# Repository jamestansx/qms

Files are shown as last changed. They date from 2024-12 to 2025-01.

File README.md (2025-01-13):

# Queue Management System

## TODO
- [x] update queue to wearables to vibrate
- [x] fix bug where queue is not updating its priority

## SETUP

- User UI:
```sh
$ # To run the app
$ fvm flutter run --dart-define=BASEURL=<api-url>
$ # To build the app
$ fvm flutter build apk --release --dart-define=BASEURL=<api-url>
```

- Management UI:
```sh
$ # To run the app (optionally --release)
$ fvm flutter run -d web-server --web-port 8080 --web-hostname 0.0.0.0 --dart-define=BASEURL=<api-url>
```

- backend:
```sh
$ # To start the server
$ BASEURL=<api-url> cargo run --release
```

- firmware:
```sh
$ # Only for arduino-cli
$ ./build.sh <port-name>
```

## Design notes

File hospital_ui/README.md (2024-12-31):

# qms_staff

User Interface for Queue Management System (Staff Interface)

## Getting Started

This project is a starting point for a Flutter application.

A few resources to get you started if this is your first Flutter project:

- [Lab: Write your first Flutter app](https://docs.flutter.dev/get-started/codelab)
- [Cookbook: Useful Flutter samples](https://docs.flutter.dev/cookbook)

For help getting started with Flutter development, view the
[online documentation](https://docs.flutter.dev/), which offers tutorials,
samples, guidance on mobile development, and a full API reference.

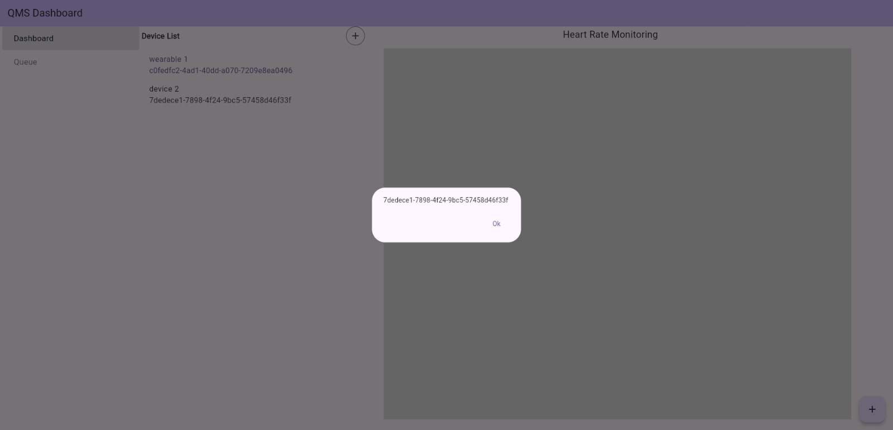
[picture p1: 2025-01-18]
docs/pictures/dashboard_add_device_uuid.jpeg

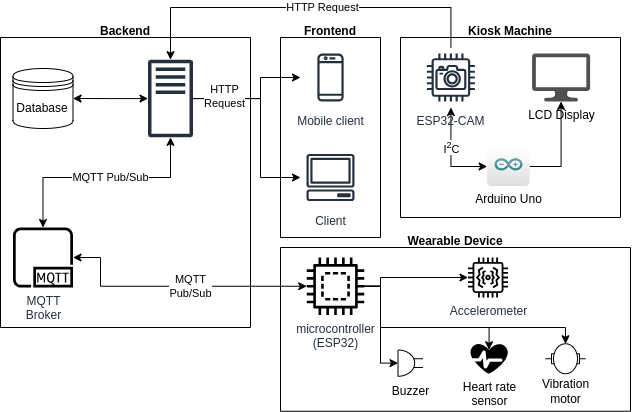
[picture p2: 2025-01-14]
docs/block_diagram.png

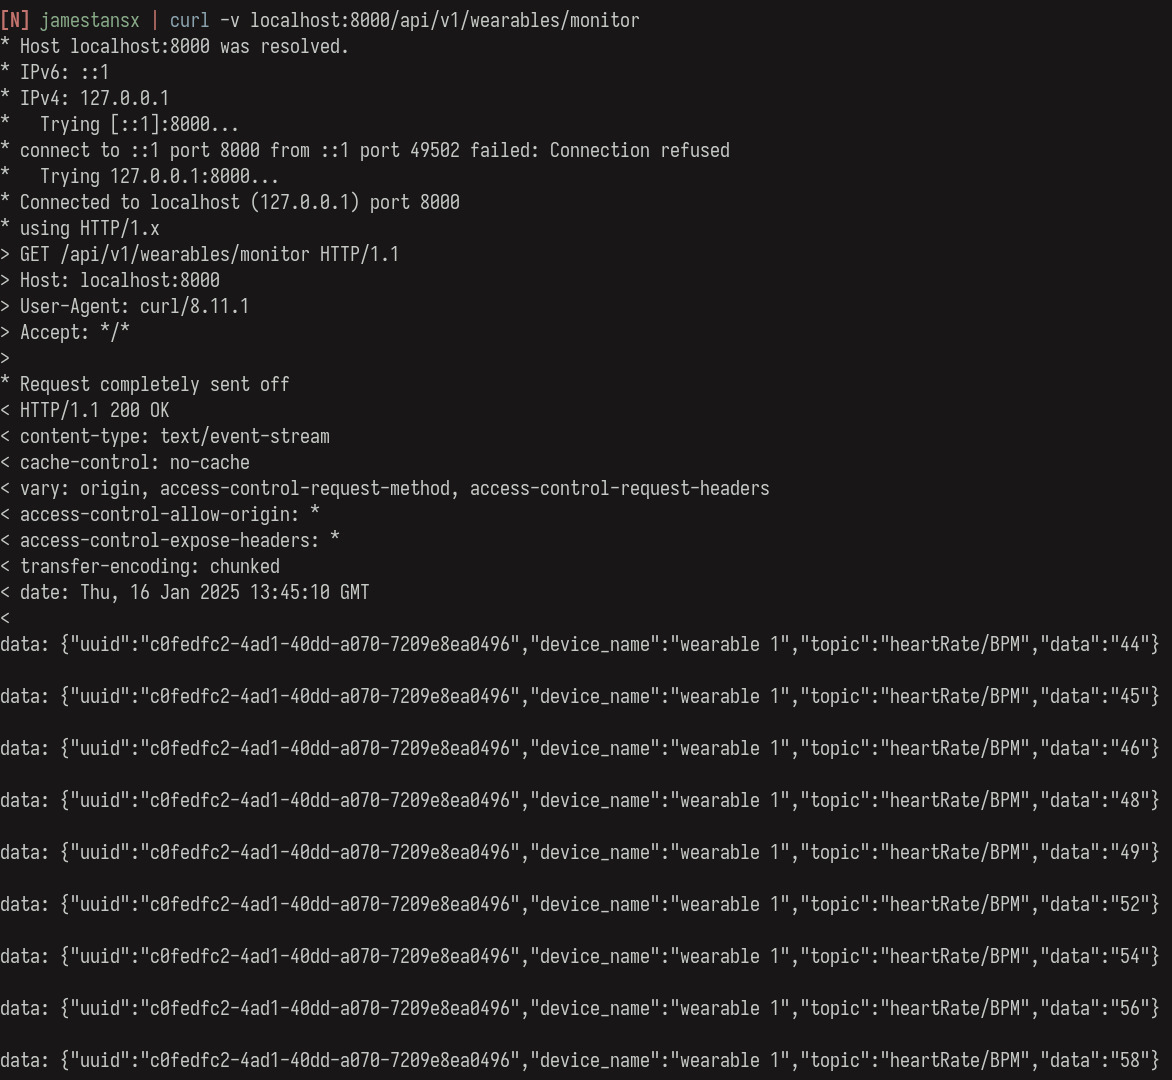
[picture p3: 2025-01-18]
docs/pictures/sse_heart_rate.jpeg

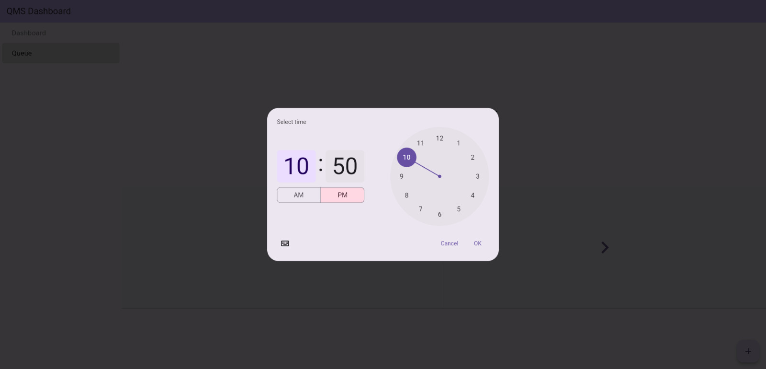
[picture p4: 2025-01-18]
docs/pictures/add_appointment_time.jpeg

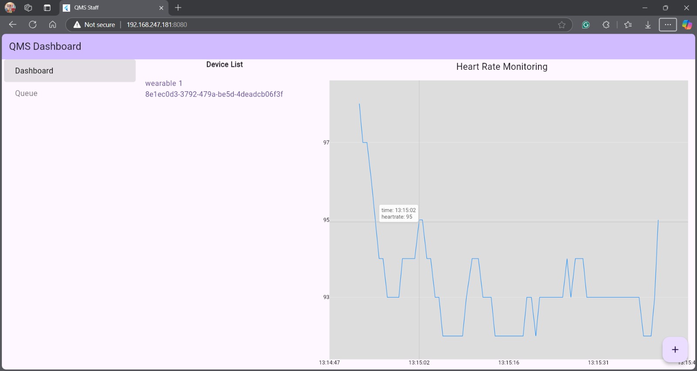
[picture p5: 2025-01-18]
docs/pictures/dashboard_heart_rate_monitor.jpeg

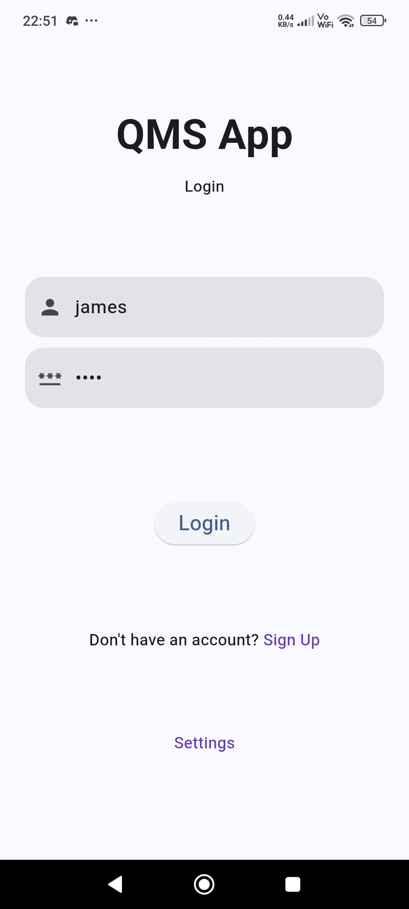
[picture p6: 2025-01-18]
docs/pictures/flutter_login_page.jpeg

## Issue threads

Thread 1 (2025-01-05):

wip(issue): Client ESP32 (wearables) failed to connect with each of two servers namely ("ESP32") and ("ESP32_1")

NgWH5555, 2025-01-05:
```cpp
//(Client ESP32, Wearables)
#include <BLEDevice.h>
#include <WiFi.h>
#include <PubSubClient.h>

const char* ssid = "DT105_2.4GHz@unifi";  // Wi-Fi SSID
const char* password = "112233DT";  // Wi-Fi Password
const char* mqtt_server = "192.168.0.7";  // MQTT Server IP
const int mqtt_port = 1883;  // MQTT Port
const char* mqtt_topic = "location/RSSI";  // MQTT Topic

WiFiClient espClient;
PubSubClient mqttClient(espClient);

static BLEUUID serviceUUID("4fafc201-1fb5-459e-8fcc-c5c9c331914b");  // Common Service UUID

// Unique Characteristic UUIDs for Beacon 1 and Beacon 2
static BLEUUID beacon1CharUUID("beb5483e-36e1-4688-b7f5-ea07361b26a8");
static BLEUUID beacon2CharUUID("beb5483e-36e1-4688-b7f5-ea07361b26a9");

static boolean doConnect = false;
static boolean connectedBeacon1 = false;
static boolean connectedBeacon2 = false;
static BLERemoteCharacteristic* pRemoteCharacteristic1;
static BLERemoteCharacteristic* pRemoteCharacteristic2;
static BLEAdvertisedDevice* myDevice = nullptr;
static BLEClient* pClient = nullptr;

int previousRSSI1 = 0;  // Previous RSSI for Beacon 1
int previousRSSI2 = 0;  // Previous RSSI for Beacon 2

// Variables to store RSSI for ESP32 and ESP32_1
int rssiESP32 = -1000;
int rssiESP32_1 = -1000;

// 1. Declare the callback class MyClientCallback before it is used
class MyClientCallback : public BLEClientCallbacks {
  void onConnect(BLEClient* pclient) {}

  void onDisconnect(BLEClient* pclient) {
    // Handle disconnect logic here
    if (pclient == pClient) {
      connectedBeacon1 = false;
      connectedBeacon2 = false;
    }
  }
};

// 2. Declare the connectToBeacon function before its usage
bool connectToBeacon(BLEAdvertisedDevice* advertisedDevice, BLEUUID beaconUUID) {
  pClient = BLEDevice::createClient();
  pClient->setClientCallbacks(new MyClientCallback());  // Use the callback here
  if (pClient->connect(advertisedDevice)) {
    Serial.println(F(" - Connected to Beacon"));

    BLERemoteService* pRemoteService = pClient->getService(serviceUUID);
    if (pRemoteService == nullptr) {
      Serial.println(F("Failed to find our service UUID"));
      pClient->disconnect();
      return false;
    }

    BLERemoteCharacteristic* pRemoteCharacteristic = pRemoteService->getCharacteristic(beaconUUID);
    if (pRemoteCharacteristic == nullptr) {
      Serial.println(F("Failed to find the characteristic for Beacon"));
      pClient->disconnect();
      return false;
    }

    return true;
  }
  return false;
}

// 3. Declare the callback class MyAdvertisedDeviceCallbacks before its usage
class MyAdvertisedDeviceCallbacks : public BLEAdvertisedDeviceCallbacks {
  void onResult(BLEAdvertisedDevice advertisedDevice) {
    Serial.print(F("BLE Advertised Device found: "));
    Serial.println(advertisedDevice.toString().c_str());

    // Capture the RSSI value
    int rssi = advertisedDevice.getRSSI();
    String deviceName = advertisedDevice.getName();

    // Check if the device is advertising the common service UUID
    if (advertisedDevice.haveServiceUUID() && advertisedDevice.isAdvertisingService(serviceUUID)) {
      BLEDevice::getScan()->stop();
      myDevice = new BLEAdvertisedDevice(advertisedDevice);

      // If it's ESP32, store the RSSI for ESP32
      if (deviceName == "ESP32") {
        rssiESP32 = rssi;
      }

      // If it's ESP32_1, store the RSSI for ESP32_1
      if (deviceName == "ESP32_1") {
        rssiESP32_1 = rssi;
      }

      // Compare the RSSI of ESP32 and ESP32_1
      if (rssiESP32 > rssiESP32_1) {
        Serial.println("Connected to ESP32 (stronger RSSI)");
        if (!connectedBeacon1) {
          if (connectToBeacon(myDevice, beacon1CharUUID)) {
            connectedBeacon1 = true;
            Serial.println("Connected to Beacon 1");
          }
        }
      } else {
        Serial.println("Connected to ESP32_1 (stronger RSSI)");
        if (!connectedBeacon2) {
          if (connectToBeacon(myDevice, beacon2CharUUID)) {
            connectedBeacon2 = true;
            Serial.println("Connected to Beacon 2");
          }
        }
      }
    }
  }
};

void connectToMQTT() {
  while (!mqttClient.connected()) {
    Serial.print(F("Connecting to MQTT..."));
    if (mqttClient.connect("ESP32_Client")) {
      Serial.println(F("connected"));
    } else {
      Serial.print(F("failed, rc="));
      Serial.print(mqttClient.state());
      delay(5000);
    }
  }
}

void scanAndConnectToBeacons() {
  BLEScan* pBLEScan = BLEDevice::getScan();
  pBLEScan->setAdvertisedDeviceCallbacks(new MyAdvertisedDeviceCallbacks());
  pBLEScan->setInterval(1349);
  pBLEScan->setWindow(449);
  pBLEScan->setActiveScan(true);
  pBLEScan->start(5, false);
}

void setup() {
  Serial.begin(115200);
  BLEDevice::init("");  // Initialize BLE device

  WiFi.begin(ssid, password);
  while (WiFi.status() != WL_CONNECTED) {
    delay(1000);
  }
  Serial.println("Connected to Wi-Fi");
  mqttClient.setServer(mqtt_server, mqtt_port);
  connectToMQTT();

  scanAndConnectToBeacons();  // Start scanning and connecting to Beacons
}

void loop() {
  if (!mqttClient.connected()) {
    connectToMQTT();
  }
  mqttClient.loop();

  // If both Beacons are connected, you can now proceed to handle other logic
  if (connectedBeacon1 && connectedBeacon2) {
    Serial.println("Both Beacons are connected!");
    // Proceed with other tasks, e.g., getting RSSI or sending MQTT messages
  } else {
    Serial.println("Waiting for connections...");
  }

  delay(2000);  // Delay to reduce the frequency of the scan loop
}

```
```cpp
//(Server1: ESP32)
#include <BLEDevice.h>
#include <BLEServer.h>
#include <BLEUtils.h>
#include <BLE2902.h>

BLEServer* pServer = NULL;
BLECharacteristic* pCharacteristic = NULL;
BLEDescriptor *pDescr;
BLE2902 *pBLE2902;

bool deviceConnected = false;
bool oldDeviceConnected = false;
uint32_t value = 0;

// See the following for generating UUIDs:
// https://www.uuidgenerator.net/

#define SERVICE_UUID        "4fafc201-1fb5-459e-8fcc-c5c9c331914b"
#define CHARACTERISTIC_UUID "beb5483e-36e1-4688-b7f5-ea07361b26a8"

class MyServerCallbacks: public BLEServerCallbacks {
    void onConnect(BLEServer* pServer) {
      deviceConnected = true;
    };

    void onDisconnect(BLEServer* pServer) {
      deviceConnected = false;
    }
};

void setup() {
  Serial.begin(115200);

  // Create the BLE Device
  BLEDevice::init("ESP32");

  // Create the BLE Server
  pServer = BLEDevice::createServer();
  pServer->setCallbacks(new MyServerCallbacks());

  // Create the BLE Service
  BLEService *pService = pServer->createService(SERVICE_UUID);

  // Create a BLE Characteristic
  pCharacteristic = pService->createCharacteristic(
                      CHARACTERISTIC_UUID,
                      BLECharacteristic::PROPERTY_NOTIFY
                    );           

  // Create a BLE Descriptor

  pDescr = new BLEDescriptor((uint16_t)0x2901);
  pDescr->setValue("A very interesting variable");
  pCharacteristic->addDescriptor(pDescr);

  pBLE2902 = new BLE2902();
  pBLE2902->setNotifications(true);
  pCharacteristic->addDescriptor(pBLE2902);

  // Start the service
  pService->start();

  // Start advertising
  BLEAdvertising *pAdvertising = BLEDevice::getAdvertising();
  pAdvertising->addServiceUUID(SERVICE_UUID);
  pAdvertising->setScanResponse(false);
  pAdvertising->setMinPreferred(0x0);  // set value to 0x00 to not advertise this parameter
  BLEDevice::startAdvertising();
  Serial.println("Waiting a client connection to notify...");
}

void loop() {
    // notify changed value
    if (deviceConnected) {
        pCharacteristic->setValue(value);
        pCharacteristic->notify();
        value++;
        delay(1000);
    }
    // disconnecting
    if (!deviceConnected && oldDeviceConnected) {
        delay(500); // give the bluetooth stack the chance to get things ready
        pServer->startAdvertising(); // restart advertising
        Serial.println("start advertising");
        oldDeviceConnected = deviceConnected;
    }
    // connecting
    if (deviceConnected && !oldDeviceConnected) {
        // do stuff here on connecting
        oldDeviceConnected = deviceConnected;
    }
}
```
```cpp
\\(Server2: ESP32_1）
#include <BLEDevice.h>
#include <BLEServer.h>
#include <BLEUtils.h>
#include <BLE2902.h>

BLEServer* pServer = NULL;
BLECharacteristic* pCharacteristic = NULL;
BLEDescriptor *pDescr;
BLE2902 *pBLE2902;

bool deviceConnected = false;
bool oldDeviceConnected = false;
uint32_t value = 0;

// See the following for generating UUIDs:
// https://www.uuidgenerator.net/

#define SERVICE_UUID        "4fafc201-1fb5-459e-8fcc-c5c9c331914b"
#define CHARACTERISTIC_UUID "beb5483e-36e1-4688-b7f5-ea07361b26a9"

class MyServerCallbacks: public BLEServerCallbacks {
    void onConnect(BLEServer* pServer) {
      deviceConnected = true;
    };
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
jamestansx, 2025-01-06:
```cpp
void perform_post_request(const char *uuid){
  // Create JSON body with the UUID
  String json_str = String("{\"uuid\": \"");
  json_str += String(uuid);
  json_str += String(\"}");

  int payload_len = json_str.length() + 1;
  char payload[payload_len];
  json_str.toCharArray(payload, payload_len);

  esp_http_client_config_t config = {
    .url = "http://192.168.0.2:3000/api/v1/queues/verify", //Full URL
  };

  esp_http_client_handle_t client = esp_http_client_init(&config);

  if(client == NULL){
    ESP_LOGE(TAG, "Failed to initialize HTTP client");
    return;
  }

  // Set POST method
  esp_http_client_set_method(client, HTTP_METHOD_POST);

  // Set POST body
  esp_http_client_set_post_field(client, payload, strlen(payload));

  // Add headers if necessary (e.g., Content-Type)
  esp_http_client_set_header(client, "Content-Type", "application/json");

  //Perform POST request
  esp_err_t err = esp_http_client_perform(client);
  if (err == ESP_OK) {
        ESP_LOGI(TAG, "HTTP POST Status = %d, content_length = %" PRId64,
                 esp_http_client_get_status_code(client),
                 esp_http_client_get_content_length(client));
    } else {
        ESP_LOGE(TAG, "HTTP POST request failed: %s", esp_err_to_name(err));
    }

  // Clean up
  esp_http_client_cleanup(client);
}

```

jamestansx, 2025-01-06:
```cpp
#define MAX_HTTP_OUTPUT_BUFFER 2048
// #define MIN(x, y) ((x < y) ? x : y)

esp_err_t _http_ev_handler(esp_http_client_event_t *ev)
{
  static char *out_buf;
  static int out_len;

  if (ev->event_id != HTTP_EVENT_ON_DATA) {
    return ESP_OK;
  }

  if (out_len == 0 && ev->user_data) {
    memset(ev->user_data, 0, MAX_HTTP_OUTPUT_BUFFER);
  }

  if (esp_http_client_is_chunked_response(ev->client)) {
    return ESP_OK;
  }

  int copy_len = 0;
  if (ev->user_data) {
    // The last byte in ev->user_data is kept for the NULL character in case of out-of-bound access.
    copy_len = MIN(ev->data_len, (MAX_HTTP_out_buf - out_len));
    if (copy_len) {
      memcpy(ev->user_data + out_len, ev->data, copy_len);
    }
  } else {
    int content_len = esp_http_client_get_content_length(ev->client);
    if (out_buf == NULL) {
      out_buf = (char *) calloc(content_len + 1, sizeof(char));
      out_len = 0;
      if (out_buf == NULL) {
        return ESP_FAIL;
      }
    }
    copy_len = MIN(ev->data_len, (content_len - out_len));
    if (copy_len) {
      memcpy(out_buf + out_len, ev->data, copy_len);
    }
  }
  out_len += copy_len;
}

.event_handler = _http_ev_handler;
```

jamestansx, 2025-01-06:
```cpp
esp_err_t _http_ev_handler(esp_http_client_event_t *ev)
{
  static char *out_buf;

  if (ev->event_id != HTTP_EVENT_ON_DATA) {
    return ESP_OK;
  }

  if (esp_http_client_is_chunked_response(ev->client)) {
    return ESP_OK;
  }

  Serial.println("I2C transmission started");
  Wire.beginTransmission(4);
  Wire.write((const uint8_t*)ev->data,ev->data_len);
  Wire.endTransmission();

  return ESP_OK;
}
```

Closed 2025-01-08.

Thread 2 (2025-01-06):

Wearables integration issue

NgWH5555, 2025-01-06:
```cpp
(1. the notification of fall detection process takes so slow like after 10 s to complete)
#define USE_ARDUINO_INTERRUPTS true    // Set up low-level interrupts for accurate BPM math.
#include <BLEDevice.h>
#include <WiFi.h>

#include <PubSubClient.h>
#include <PulseSensorPlayground.h>     // Includes the PulseSensorPlayground Library.

#include <Wire.h>
#include <MPU6050.h>                   // Ensure the MPU6050 library is compatible with ESP32.
#include <math.h>

#define SIZEOF(a) (sizeof(a) / sizeof(*a))

#define DEVICE_UUID "0ea57b2b-8dbe-41cd-9780-f7d1d237839c"

//In the DT house
const char* ssid = "DT105_2.4GHz@unifi";
const char* password = "112233DT";
const char* mqtt_server = "192.168.0.7";

//UTeM
//const char* ssid = "UTeM-Net";
//const char* password = "1UTeM@PPPK";
//const char* mqtt_server = "10.131.129.57";

////Ng
//const char* ssid = "Michael NG";
//const char* password = "weihan123456";
//const char* mqtt_server = "172.20.10.3";

const int mqtt_port = 1883;
const char* mqtt_topic_location= "location/RSSI";
const char* mqtt_topic_heart= "heartRate/BPM";                // Topic to publish heart rate data.
const char* mqtt_topic_heartAlert = "heartRate/heartAlert";
const char* mqtt_topic_amplitude = "accelerometer/amplitude";
const char* mqtt_topic_angular = "accelerometer/ang";
const char* mqtt_topic_fallAlert = "accelerometer/fall";      // Topic for fall detection.
const char* mqtt_sub_queue = "queue/status";                  //Topic for queue status update
WiFiClient espClient;
PubSubClient mqttClient(espClient);

//Variables: BLE
const BLEUUID known_beacons[] = {
  BLEUUID("beb5483e-36e1-4688-b7f5-ea07361b26a8"),
  BLEUUID("beb5483e-36e1-4688-b7f5-ea07361b26a9")
};
static boolean doScan = false;
static BLERemoteCharacteristic* pRemoteCharacteristic;
static BLEAdvertisedDevice* myDevice;
static BLEClient* pClient = nullptr;
int previousRSSI = 0;
BLEScan* pBLEScan;

struct BleBeacon {
  BLEUUID uuid;
  int rssi;
};
BleBeacon bleBeacons[SIZEOF(known_beacons)] = {};

//Variables: heartrate
const int PulseWire =34;       // PulseSensor PURPLE WIRE connected to GPIO36 (ADC1_CH0).
const int LED = 2;      // Onboard LED on ESP32 (usually GPIO2).
int Threshold = 550;            // Threshold value to detect beats.

bool recordingStarted = false;       // Flag to track when measurement starts
PulseSensorPlayground pulseSensor;  // Creates an instance of the PulseSensorPlayground object.

//variables: falldown
// MPU6050 Configuration
const int MPU_addr = 0x68; // I2C address of the MPU-6050
int16_t AcX, AcY, AcZ, Tmp, GyX, GyY, GyZ;
float ax = 0, ay = 0, az = 0, gx = 0, gy = 0, gz = 0;
boolean fall = false; // Stores if a fall has occurred
boolean trigger1 = false; // Stores if first trigger (lower threshold) has occurred
boolean trigger2 = false; // Stores if second trigger (upper threshold) has occurred
boolean trigger3 = false; // Stores if third trigger (orientation change) has occurred
byte trigger1count = 0; // Stores the counts past since trigger 1 was set true
byte trigger2count = 0; // Stores the counts past since trigger 2 was set true
byte trigger3count = 0; // Stores the counts past since trigger 3 was set true
int angleChange = 0;

//Time intervals for each operation
unsigned long prev_time_acce, prev_time_queue, prev_time_scan;
const int SAMPLE_INTERVAL = 100; // milliseconds

unsigned long prev_time_heart;
const int SAMPLE_INTERVAL_HEART = 100; // milliseconds

//Vibration DC motor
#define vibrationdc 23
static bool motorActive = false;
static unsigned long motorStartTime = 0;
const unsigned long motorVibrationDuration = 500;

void connectToMQTT() {
  while (!mqttClient.connected()) {
    Serial.print(F("Connecting to MQTT..."));
    if (mqttClient.connect("ESP32_Client")) {
      Serial.println(F("connected"));
      uint16_t packetIdSub = mqttClient.subscribe(mqtt_sub_queue, 2);
      Serial.print("Subscribing at QUEUE, packetId: ");
      Serial.println(packetIdSub);
      delay(3000);
    } else {
      Serial.print(F("failed, rc="));
      Serial.print(mqttClient.state());

      delay(5000);
    }
  }
}

String printAndSendRSSI() {
  String uuid = "";
  int rssi = 0;
  for (int i = 0; i < SIZEOF(bleBeacons); i++) {
    if (uuid.isEmpty()) {
      rssi = bleBeacons[i].rssi;
      uuid = bleBeacons[i].uuid.toString();
      continue;
    }

    if (bleBeacons[i].rssi > rssi) {
      rssi = bleBeacons[i].rssi;
      uuid = bleBeacons[i].uuid.toString();
    }
  }

  mqttClient.publish(mqtt_topic_location, uuid.c_str());

  return uuid;
}

class MyAdvertisedDeviceCallbacks : public BLEAdvertisedDeviceCallbacks {
  void onResult(BLEAdvertisedDevice advertisedDevice) {
    BLEUUID service = advertisedDevice.getServiceUUID();
    //Serial.print(F("BLE Advertised Device found: "));
    //Serial.println(advertisedDevice.toString().c_str());

    for (int i = 0; i < SIZEOF(known_beacons); i++) {
      if (service.equals(known_beacons[i])) {
        bleBeacons[i].uuid = service;
        bleBeacons[i].rssi = advertisedDevice.getRSSI();
      }
    }
  }
};

void connectWifi(){
  WiFi.begin(ssid, password);
  while (WiFi.status() != WL_CONNECTED) {
    delay(1000);
  }
  Serial.println("Connected to Wi-Fi");
  //Serial.print("IP address: ");
  //Serial.println(WiFi.localIP());

}

//server/queue  onMqttMessage() is responsible for obtaining MQTT message from the subscribed topic
//and controlling the (outside exp: LED). The string variable 'messageTemp' holds the MQTT message.
void onMqttMessage(char* topic, byte* payload, unsigned int length) {
  unsigned long currTime_queue = millis();

  if (currTime_queue - prev_time_queue >= SAMPLE_INTERVAL) {
    prev_time_queue = currTime_queue;
    Serial.println("\n Publish received.");
    Serial.print("Topic: ");
    Serial.println(topic);
    String messageTemp;
    for (int i = 0; i < length; i++){
      messageTemp += (char)payload[i];
    }
    Serial.print("Message: ");
    Serial.println(messageTemp);

    digitalWrite(vibrationdc, HIGH);
    motorActive = true;
    motorStartTime = millis();
  }

  //Turn off motor after the set duration
  if(motorActive && (millis() - motorStartTime >= motorVibrationDuration)){
    digitalWrite(vibrationdc, LOW);
    motorActive = false;
  }
}

void heartrate() {
  static unsigned long startTime = 0;    // To track the start time of measurement
  static unsigned long lastBeatTime = 0; // Tracks the last time data was sent
  const unsigned long interval = 500;   // Delay interval in milliseconds (adjust as needed)
  int myBPM = pulseSensor.getBeatsPerMinute();

  if (pulseSensor.sawStartOfBeat()) {
    if (!recordingStarted){
      if(startTime == 0){
        startTime = millis();
      }
      if (millis() - startTime >= 4000) {
        Serial.print(" | Heart Rate: N/A");
        recordingStarted = true; // Enable recording after 7 secondsM
        Serial.println("Recording started. Data will now be sent to the MQTT server.");
      }
    } else if (millis() - lastBeatTime >= interval) {
      lastBeatTime = millis(); // Update the last beat time
      Serial.print(" | Heart Rate: ");
      Serial.println(myBPM);
      char payload_heart[50];
      snprintf(payload_heart, 50, "{\"BPM\": %d}", myBPM); // Format data as JSON
      mqttClient.publish(mqtt_topic_heart, payload_heart);
    }
  }
}

/*
 * TODO: Falling detection algorithm description goes here.
 */
void falldown() {
  mpu_read();
  ax = (AcX - 2050) / 16384.00;
  ay = (AcY - 77) / 16384.00;
  az = (AcZ - 1947) / 16384.00;
  gx = (GyX + 270) / 131.07;
  gy = (GyY - 351) / 131.07;
  gz = (GyZ + 136) / 131.07;
  // Calculating Amplitude Vector for 3-axis
  float raw_amplitude = pow(pow(ax, 2) + pow(ay, 2) + pow(az, 2), 0.5);
  float amplitude = raw_amplitude * 10;  // Multiplied by 10 because values are between 0 to 1

  Serial.print(" | Amplitude: ");
  Serial.println(amplitude);
  // Publish acceleration magnitude to MQTT
  char payload_amplitude[50];
  snprintf(payload_amplitude, 50, "{\"Amplitude\": %.2f}", amplitude);
  mqttClient.publish(mqtt_topic_amplitude, payload_amplitude);

  if (amplitude <= 2 && trigger2 == false) { // If AM breaks lower threshold (0.4g)
    trigger1 = true;
    //Serial.println("TRIGGER 1 ACTIVATED");
  }
  if (trigger1 == true) {     // Detects initial potential fall
    trigger1count++;
    if (amplitude >= 12) { // If AM breaks upper threshold (3g)
      trigger2 = true;
      //    Serial.println("TRIGGER 2 ACTIVATED");
      trigger1 = false; trigger1count = 0;
    }
  }
  if (trigger2 == true) {   // Detects high amplitude (impact)
    trigger2count++;
    angleChange = pow(pow(gx, 2) + pow(gy, 2) + pow(gz, 2), 0.5);
    Serial.println(angleChange);
    if (angleChange >= 30 && angleChange <= 400) { // If orientation changes by between 80-100 degrees
      trigger3 = true; trigger2 = false; trigger2count = 0;
      //    Serial.println(angleChange);
      //    Serial.println("TRIGGER 3 ACTIVATED");
    }
  }
  if (trigger3 == true) {   // Monitors orientation changes (e.g. lying on the ground)
    trigger3count++;
      memset(bleBeacons, 0, sizeof(bleBeacons));
   pBLEScan->start(5, false);
    if (trigger3count >= 10) {
      angleChange = pow(pow(gx, 2) + pow(gy, 2) + pow(gz, 2), 0.5);
      //     Serial.println(angleChange);
      if ((angleChange >= 0) && (angleChange <= 10)) { // If orientation changes remain between 0-10 degrees
        fall = true; trigger3 = false; trigger3count = 0;
        //       Serial.println(angleChange);
      }

      else { // User regained normal orientation
        trigger3 = false; trigger3count = 0;
        //       Serial.println("TRIGGER 3 DEACTIVATED");
      }
    }
  }

  if (fall == true && !motorActive) { // In the event of a fall detection

    Serial.println("Fall detected!");
    // Additional logic for alerts (e.g., buzzer, SMS, LED)
    // Publish fall detection event to MQTT
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
NgWH5555, 2025-01-07:
CAN I USE THIS FOR REFRESH THE STATUS OF BLE CONNECTION)

#include <BLEDevice.h>
#include <BLEUtils.h>
#include <BLEScan.h>
#include <BLEClient.h>

#define SERVICE_UUID "your-service-uuid"
#define CHARACTERISTIC_UUID "your-characteristic-uuid"

BLEClient* pClient = nullptr;
bool deviceConnected = false;

// Function to scan for BLE devices with the specified SERVICE UUID
String findDeviceByServiceUUID(const char* serviceUUID) {
    Serial.println("Scanning for BLE devices with the specified service UUID...");
    BLEScan* pBLEScan = BLEDevice::getScan();
    pBLEScan->setActiveScan(true);
    BLEScanResults scanResults = pBLEScan->start(5);  // Scan for 5 seconds

    for (int i = 0; i < scanResults.getCount(); i++) {
        BLEAdvertisedDevice advertisedDevice = scanResults.getDevice(i);
        if (advertisedDevice.haveServiceUUID() && advertisedDevice.isAdvertisingService(BLEUUID(serviceUUID))) {
            Serial.print("Found device: ");
            Serial.println(advertisedDevice.toString().c_str());
            pBLEScan->clearResults();
            return advertisedDevice.getAddress().toString().c_str();
        }
    }

    Serial.println("No device found with the specified service UUID.");
    pBLEScan->clearResults();
    return "";  // Return an empty string if no device is found
}

// Function to connect to BLE device using its address
bool connectToServer(const String& deviceAddress) {
    if (deviceAddress == "") {
        Serial.println("No device address provided. Cannot connect.");
        return false;
    }

    Serial.println("Attempting to connect to BLE server...");
    pClient = BLEDevice::createClient();
    pClient->connect(BLEAddress(deviceAddress.c_str()));  // Connect to
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

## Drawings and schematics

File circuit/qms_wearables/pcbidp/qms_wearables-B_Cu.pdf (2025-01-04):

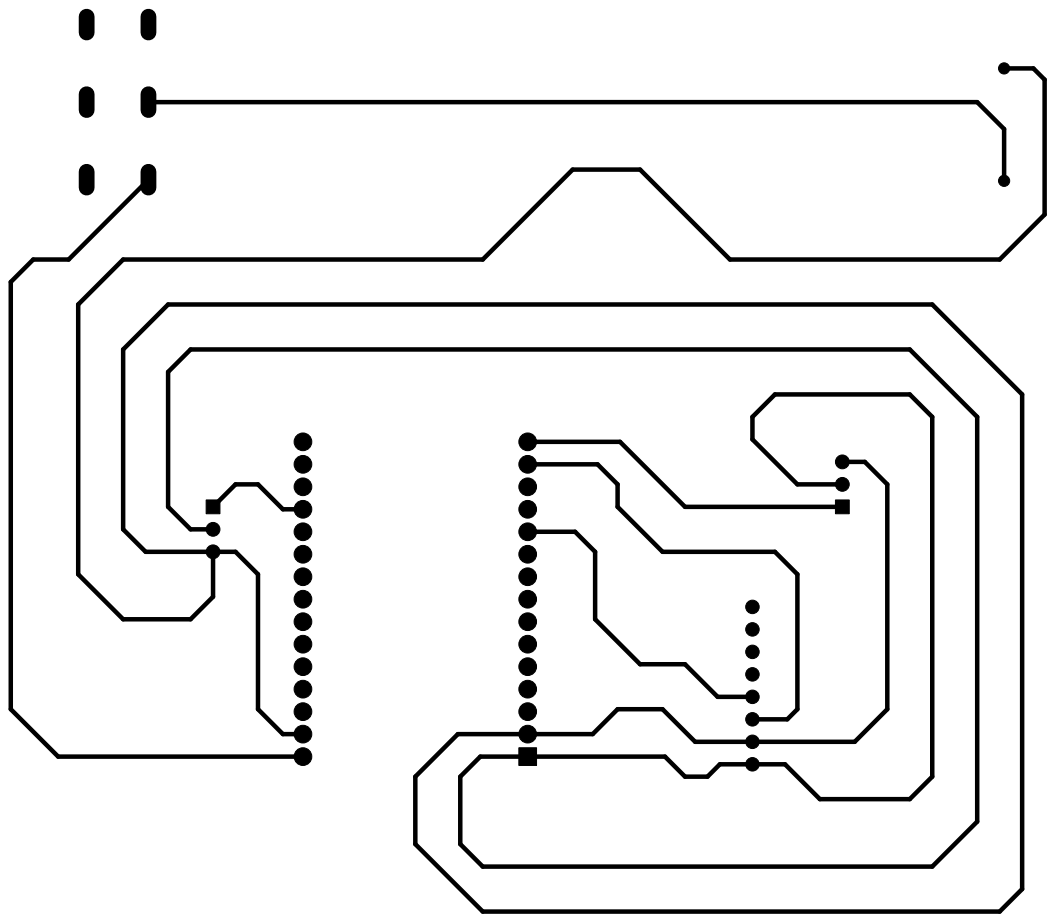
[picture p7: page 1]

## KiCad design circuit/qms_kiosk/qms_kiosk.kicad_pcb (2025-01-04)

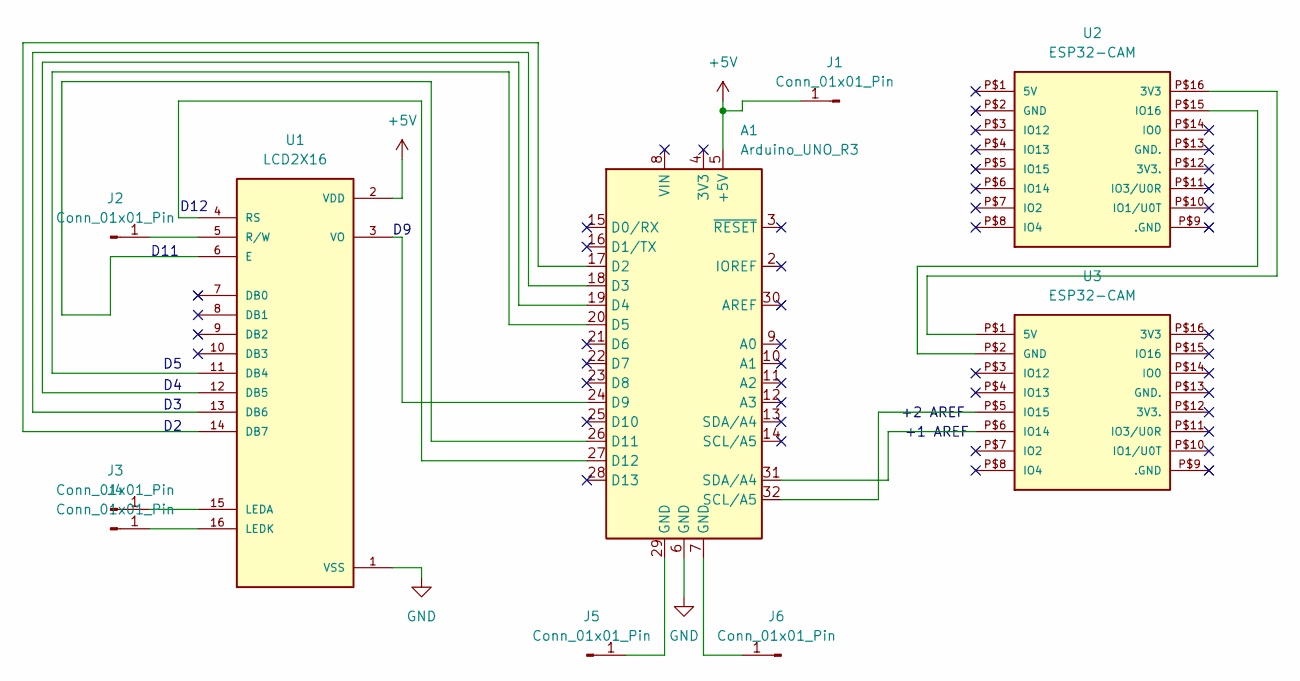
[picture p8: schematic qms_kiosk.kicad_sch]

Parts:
A1: Arduino_UNO_R3
J1, J2, J3, J4, J5, J6: Conn_01x01_Pin; PinHeader_1x01_P2.00mm_Vertical
U1: LCD2X16; LCD_LCD2X16; PARTREV 0
U2, U3: ESP32-CAM

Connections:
+5V: A1.5 (+5V), J1.1, U1.2 (VDD)
GND: A1.6 (GND), U1.1 (VSS)
unnamed: A1.17 (D2), U1.14 (DB7)
unnamed: A1.18 (D3), U1.13 (DB6)
unnamed: A1.19 (D4), U1.12 (DB5)
unnamed: A1.20 (D5), U1.11 (DB4)
unnamed: A1.24 (D9), U1.3 (VO)
unnamed: A1.26 (D11), U1.6 (E)
unnamed: A1.27 (D12), U1.4 (RS)
unnamed: J2.1, U1.5 (R/W)
unnamed: J3.1, U1.15 (LEDA)
unnamed: J4.1, U1.16 (LEDK)
unnamed: A1.29 (GND), J5.1
unnamed: A1.7 (GND), J6.1
unnamed: U2.P$16 (3V3), U3.P$1 (5V)
unnamed: U2.P$15 (IO16), U3.P$2 (GND)
unnamed: A1.31 (SDA/A4), U3.P$6 (IO14)
unnamed: A1.32 (SCL/A5), U3.P$5 (IO15)

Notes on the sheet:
D11
+2 AREF
+1 AREF
D12

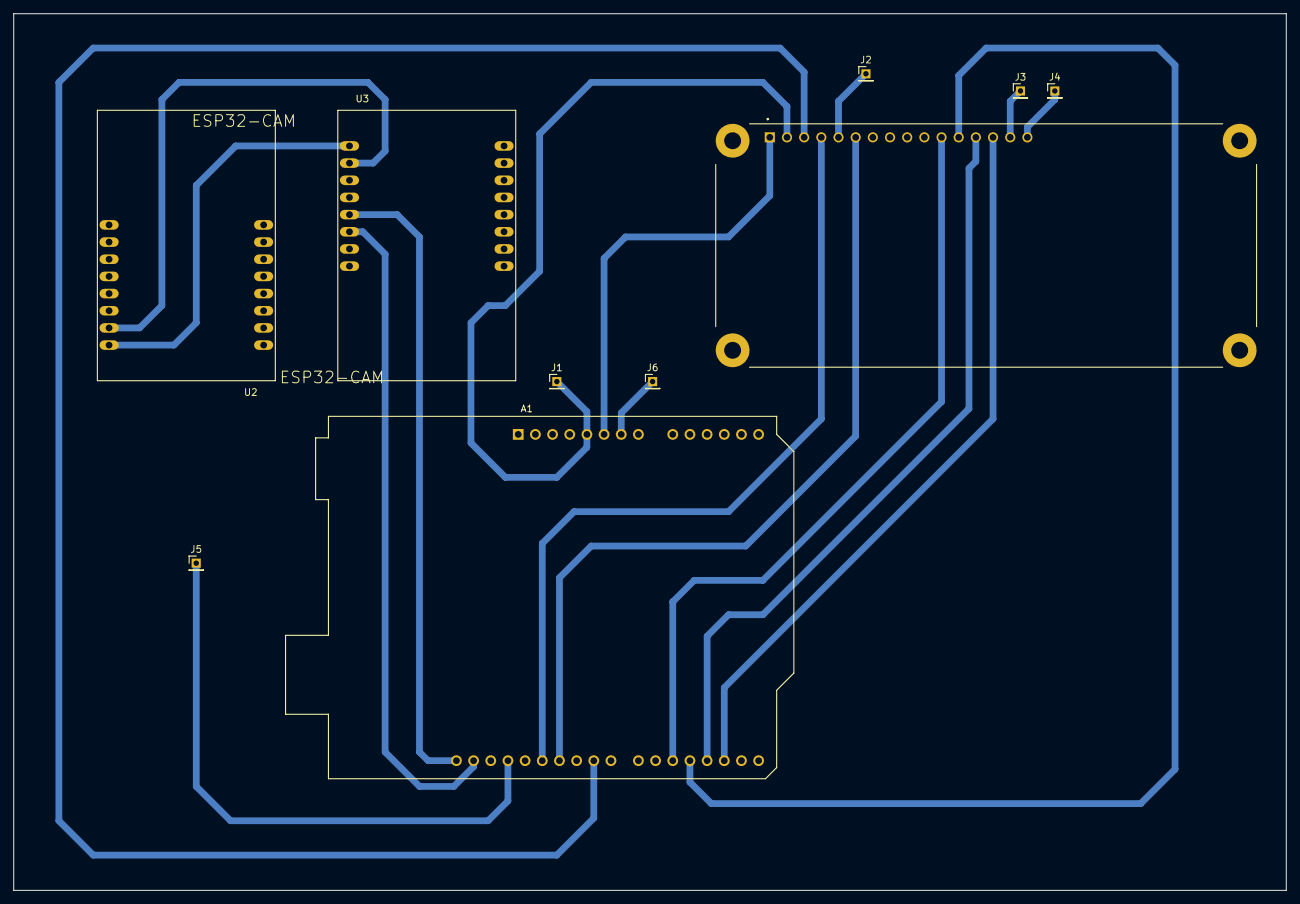
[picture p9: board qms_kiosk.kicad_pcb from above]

Board: 2 copper layers, 188.2 x 129.7 mm, 10 parts (0 on the bottom side), 18 nets.

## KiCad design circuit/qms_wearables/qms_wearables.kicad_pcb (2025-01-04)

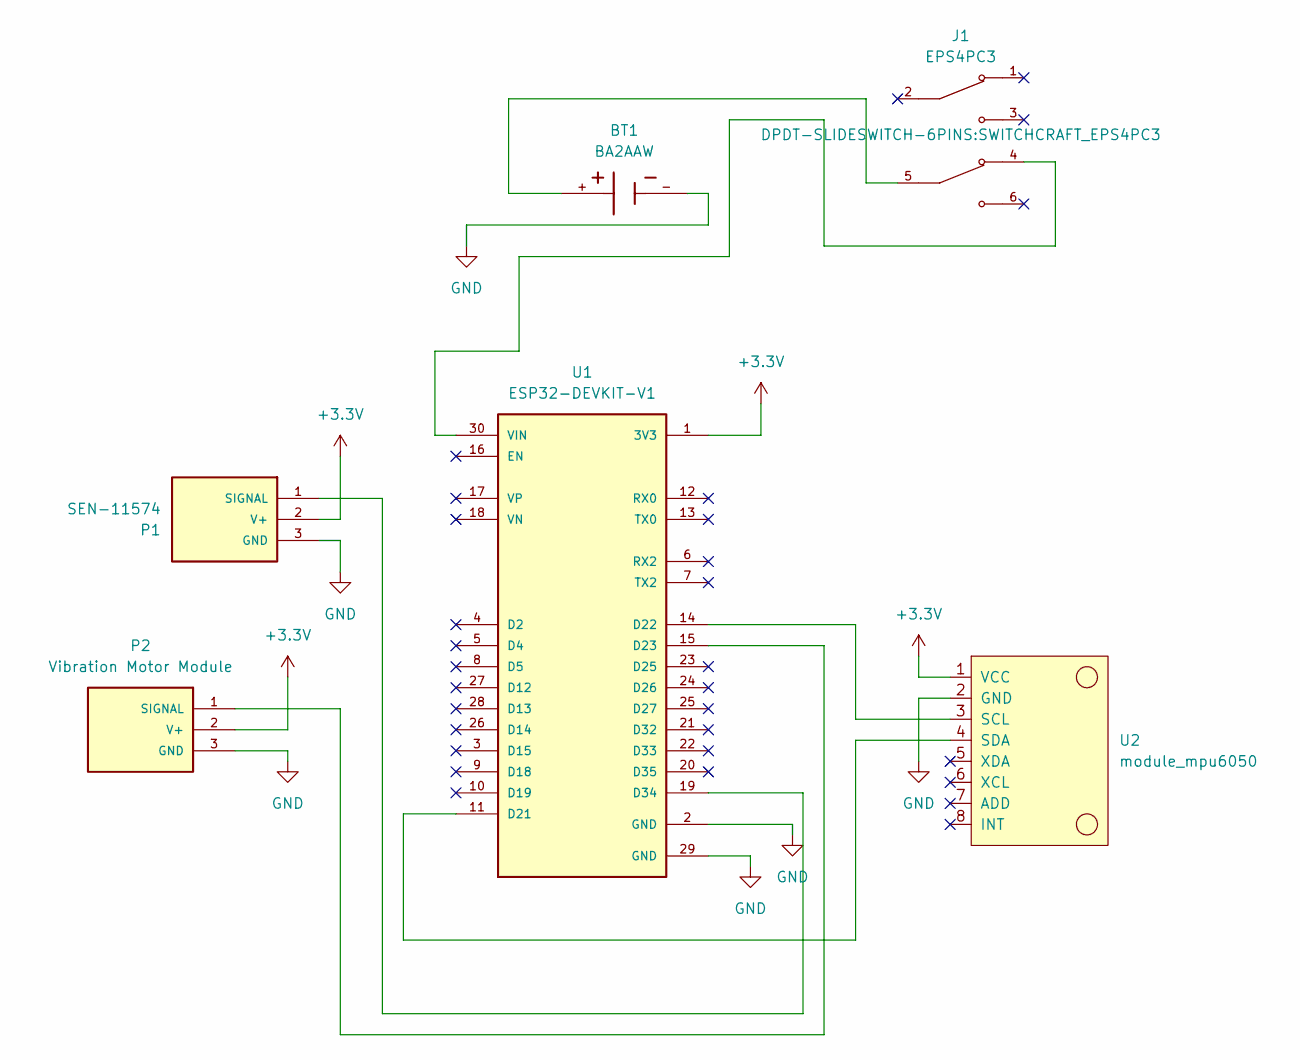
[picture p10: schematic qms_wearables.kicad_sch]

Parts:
BT1: BA2AAW; BAT_BA2AAW; PARTREV E
J1: EPS4PC3; SWITCHCRAFT_EPS4PC3
P1: SEN-11574; XDCR_SEN-11574
P2: Vibration Motor Module; XDCR_Vibration_Motor_Module
U1: ESP32-DEVKIT-V1; MODULE_ESP32_DEVKIT_V1; PARTREV N/A
U2: module_mpu6050

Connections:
+3.3V: P1.2 (V+), P2.2 (V+), U1.1 (3V3), U2.1 (VCC)
GND: BT1.-, P1.3 (GND), P2.3 (GND), U1.2 (GND), U1.29 (GND), U2.2 (GND)
unnamed: BT1.+, J1.5
unnamed: P1.1 (SIGNAL), U1.19 (D34)
unnamed: P2.1 (SIGNAL), U1.15 (D23)
unnamed: U1.11 (D21), U2.4 (SDA)
unnamed: U1.14 (D22), U2.3 (SCL)
unnamed: J1.4, U1.30 (VIN)

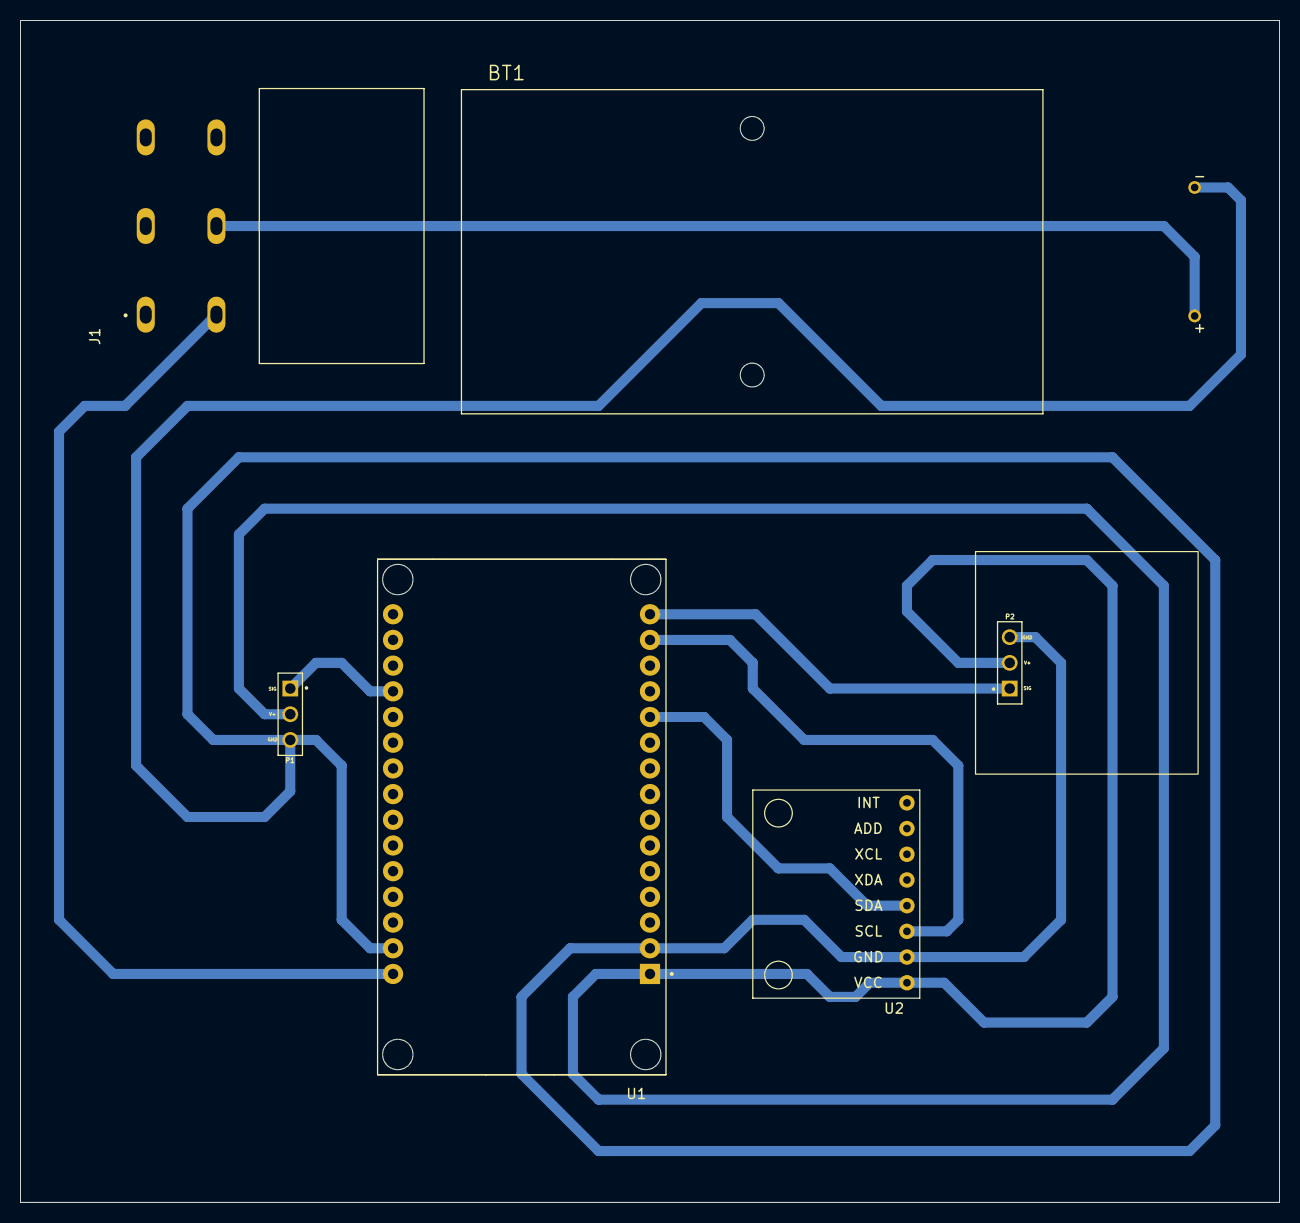
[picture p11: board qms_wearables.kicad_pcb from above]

Board: 2 copper layers, 124.5 x 116.8 mm, 6 parts (0 on the bottom side), 8 nets.

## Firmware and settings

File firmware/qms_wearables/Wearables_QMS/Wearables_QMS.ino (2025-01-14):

#include <BLEDevice.h>
#include <WiFi.h>
#include <PubSubClient.h>
#include <PulseSensorPlayground.h>
#include <Wire.h>
#include <MPU6050.h>
#include <math.h>

// Set up low-level interrupts for accurate BPM math.
#define USE_ARDUINO_INTERRUPTS true

#define SIZEOF(a) (sizeof(a) / sizeof(*a))

// NOTE: update the device uuid if changed
#define DEVICE_UUID "c0fedfc2-4ad1-40dd-a070-7209e8ea0496"
#define SAMPLE_INTERVAL_MS 100
#define SAMPLE_INTERVAL_HEART_MS 100
#define MQTT_PORT 1883

// NOTE: define the corresponding wifi
#define WEILE
#ifdef JAMESTANSX
#define SSID "jamestansx"
#define PASSWORD "james123456"
#define MQTT_SERVER "192.168.125.181"
#elif defined(WEIHAN)
#define SSID "Michael NG"
#define PASSWORD "weihan123456"
#define MQTT_SERVER "172.20.10.3"
#elif defined(UTEM)
#define SSID "UTeM-Net"
#define PASSWORD "1UTeM@PPPK"
#define MQTT_SERVER "10.131.133.70"
#elif defined(WEILE)
#define SSID "ijbol "
#define PASSWORD "09060511"
#define MQTT_SERVER "192.168.247.181"
#else
#define SSID "DT105_2.4GHz@unifi"
#define PASSWORD "112233DT"
#define MQTT_SERVER "192.168.0.2"
#endif

const char* mqtt_topic_location= "location/RSSI";
const char* mqtt_topic_heart= "heartRate/BPM";                // Topic to publish heart rate data.
const char* mqtt_topic_heartAlert = "heartRate/heartAlert";
const char* mqtt_topic_amplitude = "accelerometer/amplitude";
const char* mqtt_topic_angular = "accelerometer/ang";
const char* mqtt_topic_fallAlert = "accelerometer/fall";      // Topic for fall detection.
const char* mqtt_sub_queue = "queue/status";                  //Topic for queue status update
const char* mqtt_sub_ack = "accelerometer/ack";

WiFiClient espClient;
PubSubClient mqttClient(espClient);

// BLE
struct BleBeacon {
  BLEUUID uuid;
  int rssi;
};

const BLEUUID known_beacons[] = {
  BLEUUID("4fafc201-1fb5-459e-8fcc-c5c9c331914b"),
  BLEUUID("4fafc201-1fb5-459e-8fcc-c5c9c331914c")
};
BLEScan* pBLEScan;
BleBeacon bleBeacons[SIZEOF(known_beacons)] = {};

// Heart rate
const int PulseWire = 34;       // PulseSensor PURPLE WIRE connected to GPIO36 (ADC1_CH0).
const int LED = 2;      // Onboard LED on ESP32 (usually GPIO2).
int Threshold = 685;            // Threshold value to detect beats.
bool recordingStarted = false;       // Flag to track when measurement starts
PulseSensorPlayground pulseSensor;  // Creates an instance of the PulseSensorPlayground object.


// MPU6050 Configuration
enum FallState { safe, initial, suspect, triggered };
FallState fstate = FallState::safe;


const int MPU_addr = 0x68; // I2C address of the MPU-6050
int16_t AcX, AcY, AcZ, Tmp, GyX, GyY, GyZ;
float ax = 0, ay = 0, az = 0, gx = 0, gy = 0, gz = 0;
boolean fall = false; // Stores if a fall has occurred
boolean trigger1 = false; // Stores if first trigger (lower threshold) has occurred
boolean trigger2 = false; // Stores if second trigger (upper threshold) has occurred
boolean trigger3 = false; // Stores if third trigger (orientation change) has occurred
byte trigger1count = 0; // Stores the counts past since trigger 1 was set true
byte trigger2count = 0; // Stores the counts past since trigger 2 was set true
byte trigger3count = 0; // Stores the counts past since trigger 3 was set true
int angleChange = 0;

// non-blocking delay
unsigned long prev_time_acce, prev_time_heart;

// Vibration DC motor
#define vibrationdc 23
static bool motorActive = false;
static unsigned long motorStartTime = 0;
const unsigned long motorVibrationDuration = 5000;

// Buzzer
#define BUZZER_PIN 25

void connectToMQTT() {
  while (!mqttClient.connected()) {
    if (mqttClient.connect("ESP32_Client")) {
      mqttClient.subscribe(mqtt_sub_queue);
      mqttClient.subscribe(mqtt_sub_ack);

    } else {
      Serial.print(F("Failed to connect to MQTT with status code: "));
      Serial.println(mqttClient.state());

      delay(5000);
    }
  }
}

String printAndSendRSSI() {
  String uuid = "";
  int rssi = 0;
  for (int i = 0; i < SIZEOF(bleBeacons); i++) {
    if (uuid.isEmpty() && bleBeacons[i].rssi < 0) {
      rssi = bleBeacons[i].rssi;
      uuid = bleBeacons[i].uuid.toString();
      continue;
    }

    if (bleBeacons[i].rssi < 0 && bleBeacons[i].rssi > rssi) {
      rssi = bleBeacons[i].rssi;
      uuid = bleBeacons[i].uuid.toString();
    }
  }

  mqttClient.publish(mqtt_topic_location, uuid.c_str());

  return uuid;
}


class MyAdvertisedDeviceCallbacks : public BLEAdvertisedDeviceCallbacks {
  void onResult(BLEAdvertisedDevice advertisedDevice) {
    BLEUUID service = advertisedDevice.getServiceUUID();

    for (int i = 0; i < SIZEOF(known_beacons); i++) {
      if (service.equals(known_beacons[i])) {
        bleBeacons[i].uuid = service.toString();
        bleBeacons[i].rssi = advertisedDevice.getRSSI();
      }
    }
  }
};

void connectWifi(){
  WiFi.begin(SSID, PASSWORD);
  while (WiFi.status() != WL_CONNECTED) {
    delay(1000);
  }
  Serial.print("Connected to Wi-Fi. IP address: ");
  Serial.println(WiFi.localIP());

}

void onMqttMessage(char* topic, byte* payload, unsigned int length) {
  String messageTemp;
  for (int i = 0; i < length; i++){
    messageTemp += (char)payload[i];
  }
//  Serial.println(topic);
//  Serial.print("size topic: ");
//  Serial.println(SIZEOF(topic));
//  Serial.println(mqtt_sub_ack);
//  Serial.print("size ack: ");
//  Serial.println(SIZEOF(mqtt_sub_ack));
  if (strncmp(topic, mqtt_sub_ack, SIZEOF(mqtt_sub_ack)) == 0) {
    digitalWrite(BUZZER_PIN, LOW);
    return;
  }

  Serial.println("Receive mqtt");
  if (strncmp(DEVICE_UUID, messageTemp.c_str(), length) == 0) {
    Serial.println("TRUE");
    digitalWrite(vibrationdc, HIGH);
    motorActive = true;
    motorStartTime = millis();
  } else {
    Serial.println("FALSE");
    digitalWrite(vibrationdc, LOW);
  }

}

void heartrate() {
  if (pulseSensor.sawStartOfBeat()) {
    int myBPM = pulseSensor.getBeatsPerMinute();
    Serial.print(" | Heart Rate: ");
    Serial.println(myBPM);
    String payload_heart = String("{\"uuid\": \"");
    payload_heart.concat(DEVICE_UUID);
    payload_heart.concat("\", \"data\": { \"BPM\": \"");
    payload_heart.concat(String(myBPM));
    payload_heart.concat("\"}}");
    mqttClient.publish(mqtt_topic_heart, payload_heart.c_str());
  }
}

/*
 * TODO: Falling detection algorithm description goes here.
 */
void falldown() {
  mpu_read();
  ax = (AcX - 2050) / 16384.00;
  ay = (AcY - 77) / 16384.00;
  az = (AcZ - 1947) / 16384.00;
  gx = (GyX + 270) / 131.07;
  gy = (GyY - 351) / 131.07;
  gz = (GyZ + 136) / 131.07;
  // Calculating Amplitude Vector for 3-axis
  float raw_amplitude = pow(pow(ax, 2) + pow(ay, 2) + pow(az, 2), 0.5);
  float amplitude = raw_amplitude * 10;  // Multiplied by 10 because values are between 0 to 1 m/s^2 normal = 1g

  Serial.print(" | Amplitude: ");
  Serial.println(amplitude);

  // Publish acceleration magnitude to MQTT
  char payload_amplitude[50];
  snprintf(payload_amplitude, 50, "{\"Amplitude\": %.2f}", amplitude);
  mqttClient.publish(mqtt_topic_amplitude, payload_amplitude);

  if (amplitude <= 2 && trigger2 == false) { // If AM breaks lower threshold (0.4g)
    trigger1 = true;
  }
  if (trigger1 == true) {     // Detects initial potential fall
    trigger1count++;
    if (amplitude >= 12) { // If AM breaks upper threshold (3g)
      trigger2 = true;
      trigger1 = false;
      trigger1count = 0;
    }
  }
  if (trigger2 == true) {   // Detects high amplitude (impact)
    trigger2count++;
    angleChange = pow(pow(gx, 2) + pow(gy, 2) + pow(gz, 2), 0.5);
    if (angleChange >= 30 && angleChange <= 400) { // If orientation changes by between 80-100 degrees
      trigger3 = true;
      trigger2 = false;
      trigger2count = 0;
    }
  }
  if (trigger3 == true) {   // Monitors orientation changes (e.g. lying on the ground)
    trigger3count++;

    if (trigger3count >= 10) {
      angleChange = pow(pow(gx, 2) + pow(gy, 2) + pow(gz, 2), 0.5);
      if ((angleChange >= 0) && (angleChange <= 10)) { // If orientation changes remain between 0-10 degrees
        fall = true; trigger3 = false; trigger3count = 0;
      } else { // User regained normal orientation
        trigger3 = false;
        trigger3count = 0;
      }
    }
  }

  if (fall == true) { // In the event of a fall detection
    digitalWrite(BUZZER_PIN, HIGH);
    memset(bleBeacons, 0, sizeof(bleBeacons));
    pBLEScan->start(3, false);

    String location = printAndSendRSSI();
    String fallAlert = String("{\"uuid\": \"");
    fallAlert.concat(DEVICE_UUID);
    fallAlert.concat("\", \"data\": { \"location\": \"");
    fallAlert.concat(location);
    fallAlert.concat("\"}}");
    mqttClient.publish(mqtt_topic_fallAlert, fallAlert.c_str());

    fall = false;
  }

  if (trigger2count >= 6) { // Allow 0.5s for orientation change
    trigger2 = false;
    trigger2count = 0;
  }
  if (trigger1count >= 6) { // Allow 0.5s for AM to break upper threshold
    trigger1 = false;
    trigger1count = 0;
  }
}

void mpu_read() {
  Wire.beginTransmission(MPU_addr);
  Wire.write(0x3B);  // Starting with register 0x3B (ACCEL_XOUT_H)
  Wire.endTransmission(false);
  Wire.requestFrom(MPU_addr, 14, true);  // Request a total of 14 registers
  AcX = Wire.read() << 8 | Wire.read();  // 0x3B (ACCEL_XOUT_H) & 0x3C (ACCEL_XOUT_L)
  AcY = Wire.read() << 8 | Wire.read();  // 0x3D (ACCEL_YOUT_H) & 0x3E (ACCEL_YOUT_L)
  AcZ = Wire.read() << 8 | Wire.read();  // 0x3F (ACCEL_ZOUT_H) & 0x40 (ACCEL_ZOUT_L)
  Tmp = Wire.read() << 8 | Wire.read();  // 0x41 (TEMP_OUT_H) & 0x42 (TEMP_OUT_L)
  GyX = Wire.read() << 8 | Wire.read();  // 0x43 (GYRO_XOUT_H) & 0x44 (GYRO_XOUT_L)
  GyY = Wire.read() << 8 | Wire.read();  // 0x45 (GYRO_YOUT_H) & 0x46 (GYRO_YOUT_L)
  GyZ = Wire.read() << 8 | Wire.read();  // 0x47 (GYRO_ZOUT_H) & 0x48 (GYRO_ZOUT_L)
}

void setup() {
  Serial.begin(115200);

  //configure for ble
  BLEDevice::init("");

  pBLEScan = BLEDevice::getScan();
  pBLEScan->setAdvertisedDeviceCallbacks(new MyAdvertisedDeviceCallbacks());
  pBLEScan->setInterval(1349);
  pBLEScan->setWindow(449);
  pBLEScan->setActiveScan(true);
  pBLEScan->start(5, false);

  // Configure for heartrate
  // NOTE: ESP32 ADC resolution defaults to 12 bits.
  // PulseSensor rquires 10 bits
  analogReadResolution(10);
  pulseSensor.analogInput(PulseWire);
  pulseSensor.blinkOnPulse(LED);  // Blink the onboard LED with a heartbeat.
  pulseSensor.setSerial(Serial);
  pulseSensor.setThreshold(Threshold);
  while (!pulseSensor.begin());

  //configure for falldown
  Wire.begin();
  Wire.beginTransmission(MPU_addr);
  Wire.write(0x6B);  // PWR_MGMT_1 register
  Wire.write(0);     // Set to zero (wakes up the MPU-6050)
  Wire.endTransmission(true);

  connectWifi();

  mqttClient.setServer(MQTT_SERVER, MQTT_PORT);
  mqttClient.setCallback(onMqttMessage);

  pinMode(vibrationdc, OUTPUT);
  pinMode(BUZZER_PIN, OUTPUT);
  digitalWrite(BUZZER_PIN, LOW);
  digitalWrite(vibrationdc, LOW);
}

void loop() {
  if (!mqttClient.connected()) {
    connectToMQTT();
  }
  mqttClient.loop();

  heartrate();
  nb_delay(falldown, prev_time_acce, SAMPLE_INTERVAL_MS);

  //Turn off motor after the set duration
//  if(motorActive && (millis() - motorStartTime >= motorVibrationDuration)){
//    digitalWrite(vibrationdc, LOW);
//    motorActive = false;
//  }

  // clear BLEScan buffer to release memory
  pBLEScan->clearResults();
}

void nb_delay(void (*func)(), unsigned long &prev_sampled_time, unsigned long sampling_interval) {
  unsigned long curr_time = millis();
  if (curr_time - prev_sampled_time >= sampling_interval) {
    prev_sampled_time = curr_time;
    func();
  }
}

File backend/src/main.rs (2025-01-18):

use std::{
    collections::HashMap,
    env,
    str::FromStr,
    sync::{Arc, RwLock},
    time::Duration,
};

use axum::{
    extract::{MatchedPath, Request},
    Router,
};
use routes::make_routes;
use rumqttc::{mqttbytes::QoS, AsyncClient, Event, EventLoop, MqttOptions, Packet::Publish};
use sqlx::{sqlite::SqliteConnectOptions, SqlitePool};
use states::*;
use tokio::{net::TcpListener, sync::broadcast, task};
use tower_http::{cors::CorsLayer, trace::TraceLayer};
use tracing_subscriber::{layer::SubscriberExt, util::SubscriberInitExt};

mod error;
mod handlers;
mod models;
mod queue;
mod routes;
mod states;
mod test;

async fn init_db(db_uri: &str) -> Result<SqlitePool, sqlx::Error> {
    let opts = SqliteConnectOptions::from_str(db_uri)?.create_if_missing(true);
    let pool = SqlitePool::connect_with(opts).await?;
    sqlx::migrate!("./migrations").run(&pool).await?;
    Ok(pool)
}

async fn init_mqtt_client() -> Result<(AsyncClient, EventLoop), rumqttc::ClientError> {
    let mut mqtt_opts = MqttOptions::new("qms_server_mqtt", "0.0.0.0", 1883);
    mqtt_opts.set_keep_alive(Duration::from_secs(5));
    let (cl, event_loop) = AsyncClient::new(mqtt_opts, 10);
    cl.subscribe("heartRate/BPM", QoS::AtMostOnce).await?;
    cl.subscribe("accelerometer/fall", QoS::AtMostOnce).await?;

    Ok((cl, event_loop))
}

#[tokio::main]
async fn main() -> Result<(), Box<dyn std::error::Error>> {
    tracing_subscriber::registry()
        .with(tracing_subscriber::fmt::layer())
        .init();

    let pool = init_db("sqlite://qms.db").await?;

    let (tx, _) = broadcast::channel(100);
    let (tx_subs, _) = broadcast::channel::<MqttPayload>(100);
    let (tx_fall, _) = broadcast::channel::<()>(100);
    let iot = IotState {
        tx_subscribe: tx_subs.clone(),
        wearables: Arc::new(RwLock::new(HashMap::new())),
        tx_fall: tx_fall.clone(),
    };
    let state = Arc::new(AppState::new(pool, tx.clone(), iot));

    // mqtt client
    let (cl, mut event_loop) = init_mqtt_client().await?;
    let mqtt_client = task::spawn(async move {
        let mut rx = tx.subscribe();
        let mut rx_fall = tx_fall.subscribe();
        loop {
            if let Ok(recv) = rx.try_recv() {
                if let Some(recv) = recv.map(|x| x.1) {
                    tracing::info!("queue/status: publish {recv:?}");
                    cl.publish(
                        "queue/status",
                        QoS::AtMostOnce,
                        false,
                        recv.unwrap_or("NONE".into()),
                    )
                    .await
                    .ok();
                } else {
                    tracing::info!("receive NONE");
                    cl.publish("queue/status", QoS::AtMostOnce, false, "NONE")
                        .await
                        .ok();
                }
            }

            if rx_fall.try_recv().is_ok() {
                cl.publish("accelerometer/ack", QoS::AtMostOnce, false, "")
                    .await
                    .ok();
            }

            /*
            {
                "uuid": "<generated-uuid>", // uuid of the wearables
                "topic": "<topic of the publisher>",
                "data": {
                    // any data published
                    "bpm": 123,
                    "fell_down": true,
                    "location": "<location-uuid>",
                },
            }
            */
            let notif = event_loop.poll().await;
            if let Ok(Event::Incoming(Publish(publish))) = notif {
                if let Ok(payload) = std::str::from_utf8(&publish.payload) {
                    let mut res: MqttPayload = serde_json::from_str(payload).unwrap();
                    res.topic = publish.topic;
                    let _ = tx_subs.send(res);
                }
            }
        }
    });

    let app = Router::new()
        .nest("/api/v1", make_routes(state))
        .layer(
            TraceLayer::new_for_http()
                .make_span_with(|req: &Request| {
                    let method = req.method();
                    let uri = req.uri();

                    let matched_path = req
                        .extensions()
                        .get::<MatchedPath>()
                        .map(|matched_path| matched_path.as_str());

                    tracing::debug_span!("request", %method, %uri, matched_path)
                })
                .on_failure(()),
        )
        .layer(CorsLayer::permissive());

    let listener = TcpListener::bind(format!(
        "{}:8000",
        env::var("BASEURL").unwrap_or("0.0.0.0".into())
    ))
    .await?;
    tracing::debug!("listening on {}", listener.local_addr()?);
    let server = task::spawn(async { axum::serve(listener, app).await });

    let _ = tokio::join!(server, mqtt_client);

    Ok(())
}

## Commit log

2024-11-15 Ready. Set. Go!
    [qms_kiosk.kicad_pcb, qms_kiosk.kicad_sch, qms_wearables.kicad_pcb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]
2024-11-16 chore: ignore fp-info-cache
    ref: https://www.mail-archive.com/kicad-developers@lists.launchpad.net/msg32871.html
2024-11-16 feat: Add SEN_11574 symbol and footprint
2024-11-16 Add ESP32-DEVKIT-V1 symbol and footprint
2024-11-16 feat: Add MPU6050 breakout board
2024-11-16 feat: Add LCD 16x4(16x2) Display symbol and footprint
2024-11-17 feat: Add ESP32-CAM symbol and footprint
2024-11-17 feat: Add I2C module for LCD Display symbol and footprint.
2024-11-17 Draft 1: Design schematic circuit of Kiosk Machine.
    [qms_kiosk.kicad_sch]
2024-11-17 Draft 1 (Wearables): Design schematic circuit of Wearables.
    [qms_wearables.kicad_sch]
2024-11-17 fix: wrong input voltage to ESP32
    [qms_wearables.kicad_sch]
2024-11-23 wip: add patient registration endpoint
2024-11-24 Draft 1 (Kiosk): Set up Send and Receive communication betweenESP32-CAM and Arduino UNO.
2024-12-06 wip: Determine the signal strength between server and client esp32 ble.
2024-12-07 wip: Testing the MQTT for Heart Sensor and Accelerometer.
2024-12-21 wip: Modified the formula of Acceleration magnitude and angular velocity to prevent the fall detection when the accelerometer is twisted in stationary.
2024-12-21 wip: Modified the Kiosk system schematic circuit.
    [qms_kiosk.kicad_sch]
2024-12-23 wip: Update the pcb footprint of the components.
    [qms_kiosk.kicad_pcb, qms_kiosk.kicad_sch]
2024-12-23 wip: Modified the formula of acceleration magnitude and angular velocity magnitude
2024-12-23 wip: Update the pcb footprint of the components in wearables circuit.
    [qms_wearables.kicad_pcb, qms_wearables.kicad_sch]
2024-12-26 wip: First draft complete kiosk circuit.
    [qms_kiosk.kicad_pcb, qms_kiosk.kicad_sch, qms_wearables.kicad_pcb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]
2024-12-26 wip: First draft complete wearable circuit schematic and pcb with adding 2x battery, DC vibration motor module.
    [qms_wearables.kicad_pcb, qms_wearables.kicad_sch]
2024-12-28 wip: Second draft with replacing the schematic and footprint of vibration motor module
    [qms_wearables.kicad_pcb, qms_wearables.kicad_sch]
2024-12-28 wip: Replacing the code of accelerometer with changing formulae of acceleration magnitude.
2024-12-29 fix various backend issues
    [main.rs]
2024-12-30 feat: filter appointment list and display queue no. only on status
2024-12-30 wip: Second draft with reducing size of the edge cuts to fulfill the pcb board physical dimension 15cm by 30cm
    [qms_kiosk.kicad_pcb]
2024-12-30 wip: Third draft with reducing size of the edge cuts as smaller as possible
    [qms_kiosk.kicad_pcb]
2024-12-30 wip: Third draft with reducing size of the edge cuts in wearables pcb as smaller as possible
    [qms_wearables.kicad_pcb]
2024-12-31 wip: Fourth draft with replacing the DPDT Slide Switch and 2 Cell battery footprint and schematic circuit.
    [qms_wearables.kicad_pcb, qms_wearables.kicad_sch]
2024-12-31 wip: Draft for changing the pcb traces size from 0.762mm (T30) to 0.508mm(T20).
    [qms_kiosk.kicad_pcb, qms_kiosk.kicad_sch, qms_wearables.kicad_pcb]
2024-12-31 integrate iot to server
    expected incoming bugs -.-
    [main.rs]
2025-01-04 wip: First draft complete coding for wearables (Testing using MQTT Broker.
    [ESP32_Server_Sig.ino, Wearables_QMS.ino]
2025-01-04 wip: First draft complete coding for ESP32-CAM and LCD Displayof kiosk machine (Testing using MQTT Broker).
    [16x4_LCD_QMS.ino, ESP32_Cam_QR_Code_Scanner_Stream_Web_Server_QMS.ino]
2025-01-04 wip: Fifth draft change the trace size into 1mm for pcb fabrication requirement, (mistake: the distance between drill holes in the overall circuit are too short, which cause the real components canno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
    [qms_wearables-B_Cu.gbr, qms_wearables-B_Mask.gbr, qms_wearables-B_Paste.gbr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]
2025-01-04 feat: add api callback for buttons
2025-01-06 Remove the vibration feature on Heart Rate measurement and move to the mqtt subscribe part
    [Wearables_QMS.ino]
2025-01-06 fixup! feat: I don't know if it works
    [Wearables_QMS.ino]
2025-01-06 fixup! fixup! feat: I don't know if it works
    [Wearables_QMS.ino]
2025-01-08 wip: modified the codes of esp32-cam.
2025-01-09 feat: add support to vibrate motor on queue
    [Wearables_QMS.ino]
2025-01-13 feat: display assigned wearable in queue
    fix: current queue will not be overwritten
2025-01-14 chore: update device uuid
2025-01-15 feat: add button to register new wearable
2025-01-17 test: add test case for priority queue
